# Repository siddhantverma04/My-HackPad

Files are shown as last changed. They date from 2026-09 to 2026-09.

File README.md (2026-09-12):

# My HackPad

A custom 3×3 macropad designed from scratch using KiCad, Fusion 360, and QMK.

The HackPad uses a Seeed Studio XIAO RP2040, 9 mechanical switches,
4 SK6812MINI-E RGB LEDs, a 128×32 OLED display, and custom QMK firmware.

## Features

- 3×3 mechanical key layout
- 4 SK6812MINI-E RGB LEDs
- 0.91" 128×32 SSD1306 OLED
- Seeed Studio XIAO RP2040
- Custom PCB
- Custom 3D-printed case
- QMK firmware

## HackPad Render



## Schematic



## PCB



## Case

The case was designed to fit the custom PCB, switches, OLED, and XIAO RP2040. 



## Firmware

The HackPad runs QMK firmware on the XIAO RP2040.

Current normal keymap:

| 1 | 2 | 3 |
|---|---|---|
| 4 | 5 | 6 |
| 7 | 8 | 9 |

Holding key 9 opens an RGB-control layer for changing effects,
hue, saturation, and brightness.

## Bill of Materials

| Component | Amount |
|---|---:|
| Seeed Studio XIAO RP2040 | 1 |
| Cherry MX-compatible switches | 9 |
| 1N4148 diodes | 9 |
| SK6812MINI-E RGB LEDs | 4 |
| 0.91" 128×32 SSD1306 OLED | 1 |
| 1U keycaps | 9 |
| Custom PCB | 1 |
| 3D-printed top case / plate(I will print myself) | 1 |
| 3D-printed bottom case(I will print myself) | 1 |
| M3 screws | 4 |
| M3 heat-set inserts | 4 |

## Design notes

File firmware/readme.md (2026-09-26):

# My Hackpad Firmware

QMK firmware for my custom 3x3 Hackpad.

## Hardware

- Seeed Studio XIAO RP2040
- 9 Cherry MX compatible switches
- 4 SK6812MINI-E RGB LEDs
- 0.91 inch 128x32 SSD1306 I2C OLED

## Firmware

Firmware is built using QMK Firmware.

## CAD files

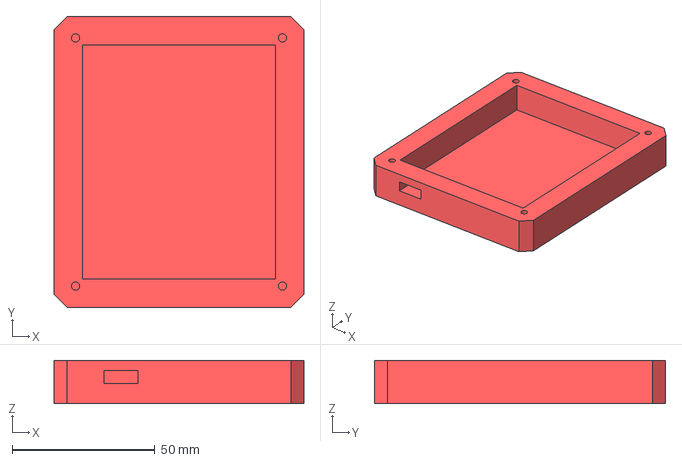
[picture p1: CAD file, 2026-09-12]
production/Bottom.step
87.5 x 102.0 x 15.2 mm

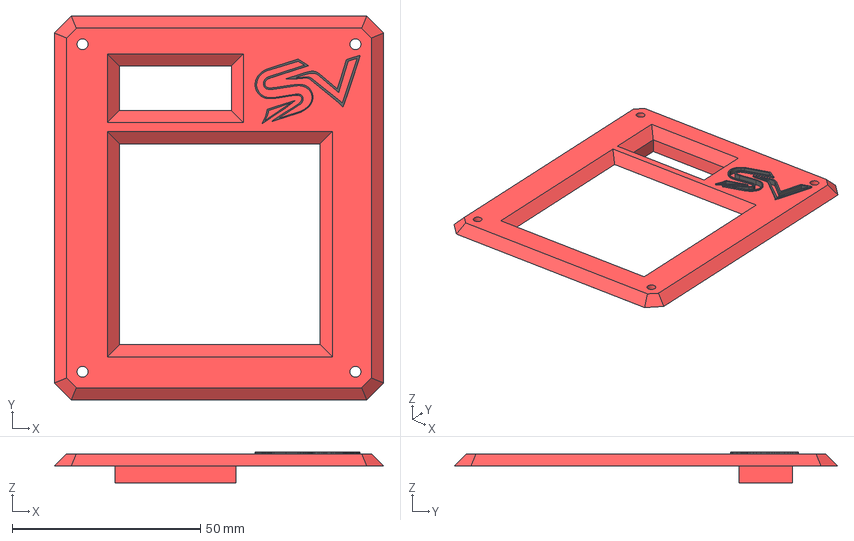
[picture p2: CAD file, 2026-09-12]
production/Top.step
87.5 x 102.0 x 8.15 mm

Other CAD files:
production/Bottom.3mf

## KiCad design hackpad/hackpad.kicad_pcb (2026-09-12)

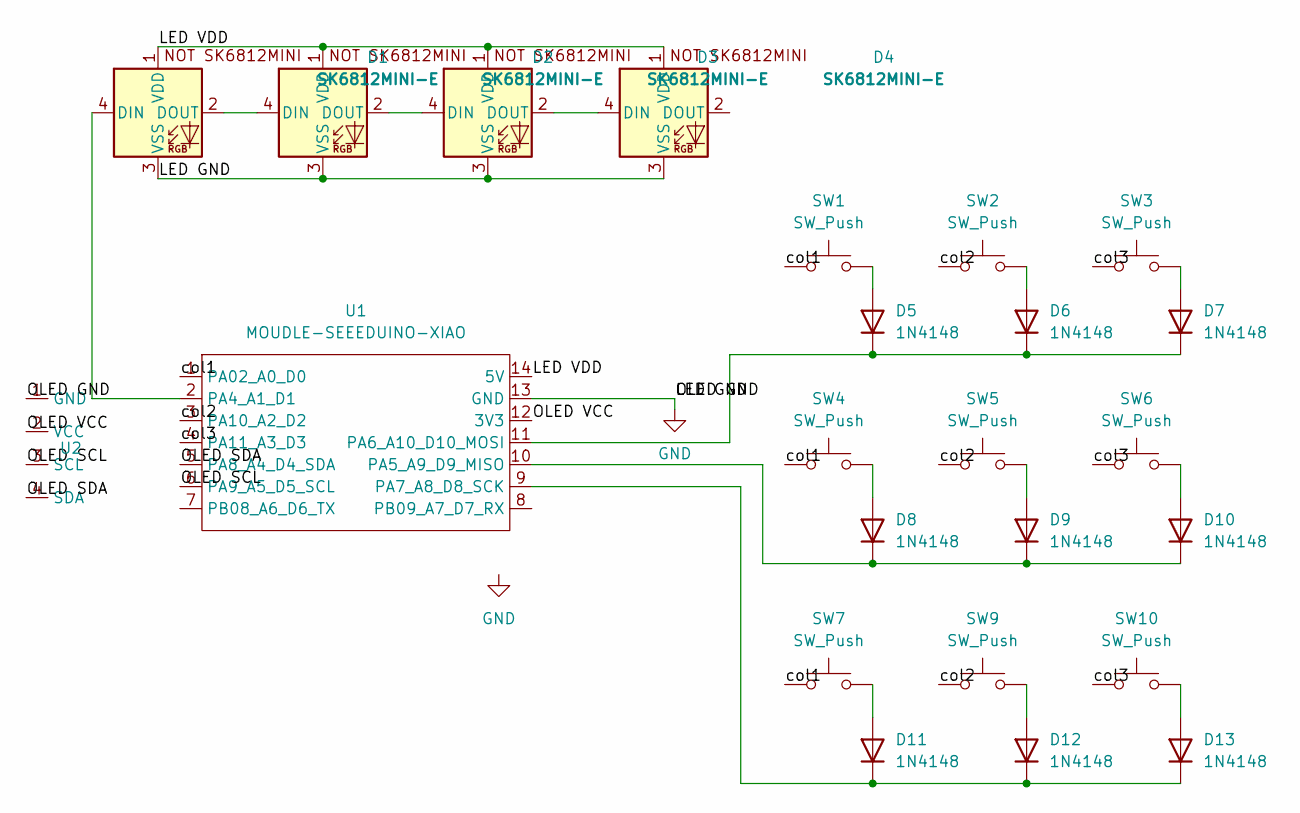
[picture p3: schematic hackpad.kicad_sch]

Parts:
D1, D2, D3, D4: SK6812MINI-E; LED_SK6812MINI-E_3.2x2.8mm_P1.5mm_ReverseMount
D5, D6, D7, D8, D9, D10, D11, D12, D13: 1N4148; D_DO-35_SOD27_P7.62mm_Horizontal
SW1, SW2, SW3, SW4, SW5, SW6, SW7, SW9, SW10: SW_Push; SW_Cherry_MX_1.00u_PCB
U1: MOUDLE-SEEEDUINO-XIAO; XIAO-Generic-Hybrid-14P-2.54-21X17.8MM
U2: SSD1306-0.91-OLED-4pin-128x32

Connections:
/<NO NET>: U1.5 (PA8_A4_D4_SDA), U2.4 (SDA)
/LED VDD: D1.1 (VDD), D2.1 (VDD), D3.1 (VDD), D4.1 (VDD), U1.14 (5V)
/OLED SCL: U1.6 (PA9_A5_D5_SCL), U2.3 (SCL)
/OLED VCC: U1.12 (3V3), U2.2 (VCC)
/col1: SW1.1, SW4.1, SW7.1, U1.1 (PA02_A0_D0)
/col2: SW2.1, SW5.1, SW9.1, U1.3 (PA10_A2_D2)
/col3: SW3.1, SW6.1, SW10.1, U1.4 (PA11_A3_D3)
GND: D1.3 (VSS), D2.3 (VSS), D3.3 (VSS), D4.3 (VSS), U1.13 (GND), U2.1 (GND)
unnamed: D1.4 (DIN), U1.2 (PA4_A1_D1)
unnamed: D1.2 (DOUT), D2.4 (DIN)
unnamed: D2.2 (DOUT), D3.4 (DIN)
unnamed: D3.2 (DOUT), D4.4 (DIN)
unnamed: D5.2 (A), SW1.2
unnamed: D5.1 (K), D6.1 (K), D7.1 (K), U1.11 (PA6_A10_D10_MOSI)
unnamed: D6.2 (A), SW2.2
unnamed: D7.2 (A), SW3.2
unnamed: D8.2 (A), SW4.2
unnamed: D9.2 (A), SW5.2
unnamed: D10.2 (A), SW6.2
unnamed: D8.1 (K), D9.1 (K), D10.1 (K), U1.10 (PA5_A9_D9_MISO)
unnamed: D11.2 (A), SW7.2
unnamed: D11.1 (K), D12.1 (K), D13.1 (K), U1.9 (PA7_A8_D8_SCK)
unnamed: D12.2 (A), SW9.2
unnamed: D13.2 (A), SW10.2

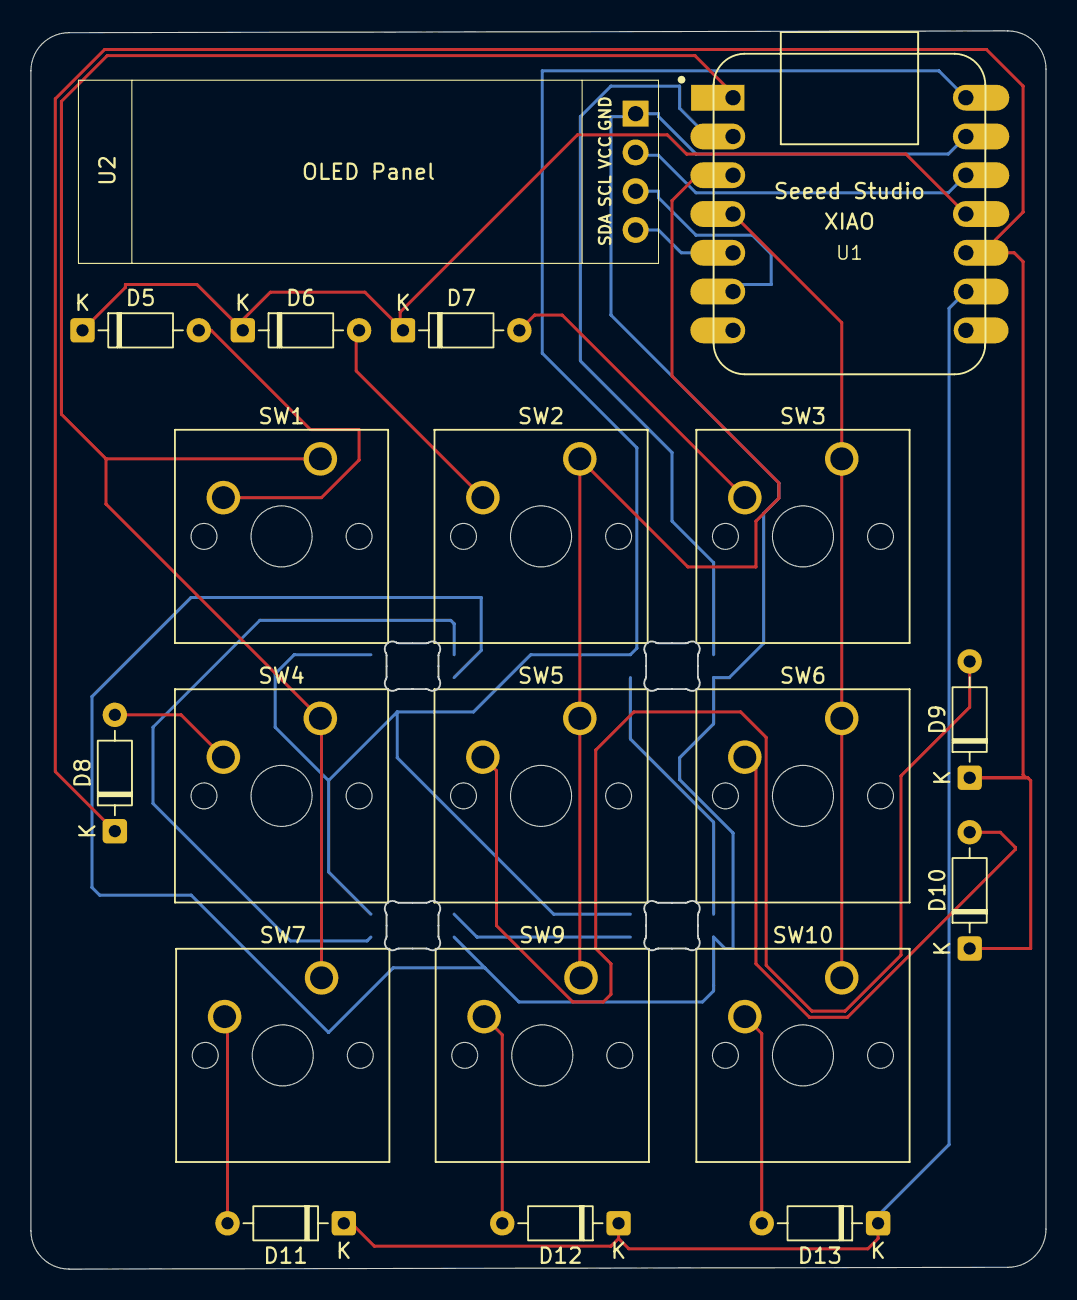
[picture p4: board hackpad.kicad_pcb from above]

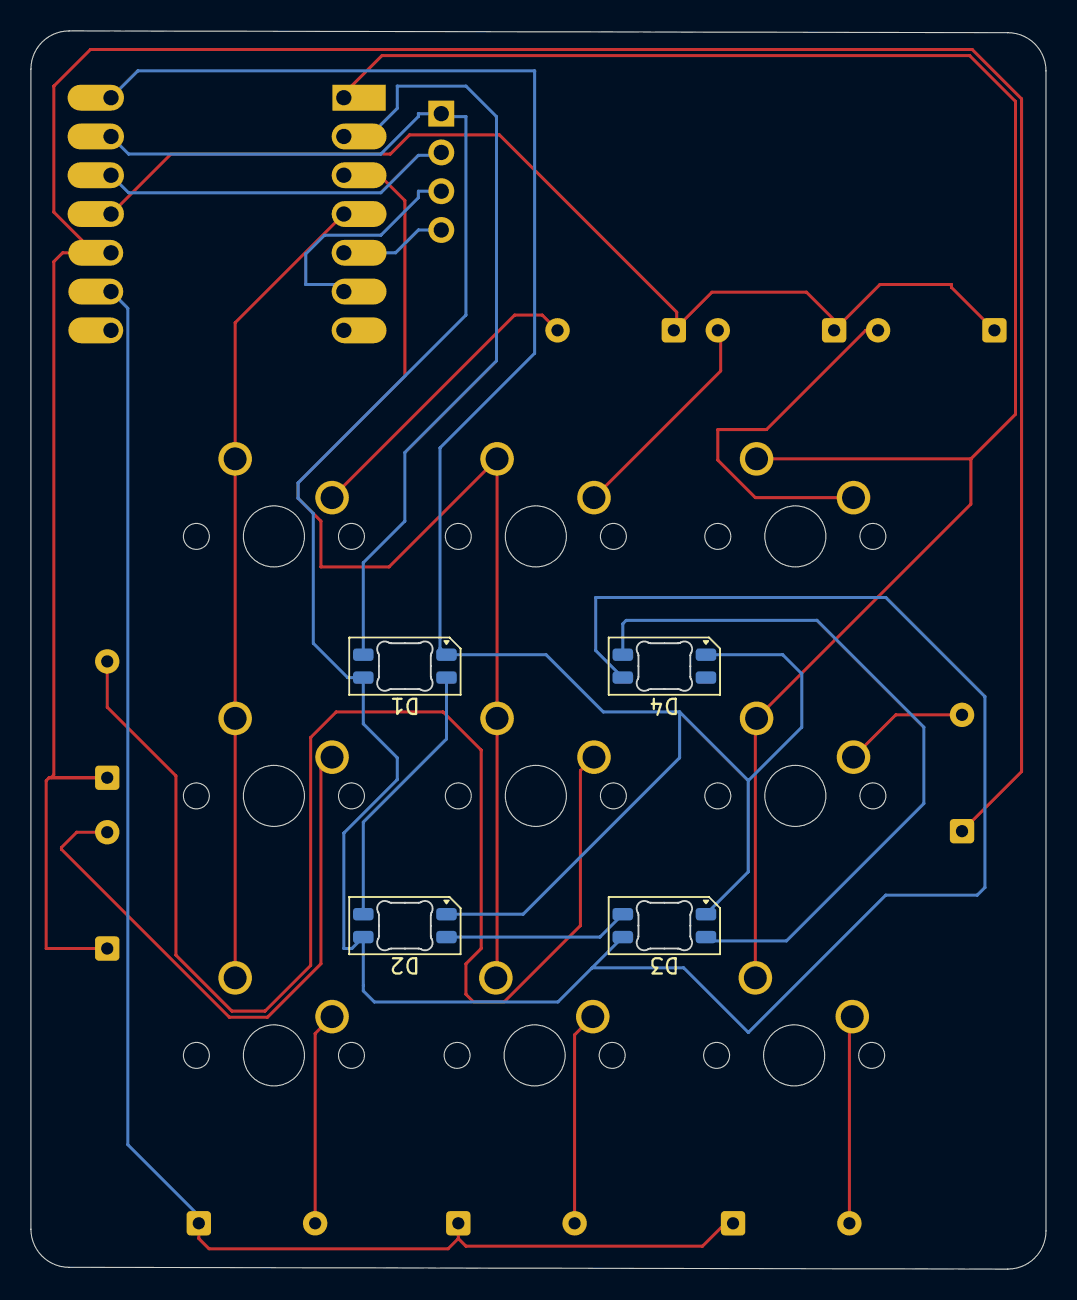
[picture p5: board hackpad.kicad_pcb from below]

Board: 2 copper layers, 66.5 x 81.1 mm, 24 parts (4 on the bottom side), 24 nets.

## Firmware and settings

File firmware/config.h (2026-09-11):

#pragma once

#define RGB_LIMIT_VAL 120
#define RGBLIGHT_SLEEP

#define I2C_DRIVER I2CD1
#define I2C1_SDA_PIN GP6
#define I2C1_SCL_PIN GP7

#define OLED_DISPLAY_ADDRESS 0x3C
#define OLED_BRIGHTNESS 128
#define OLED_TIMEOUT 60000

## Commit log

2026-08-24 Imported PCB
    [hackpad.kicad_pcb, hackpad.kicad_sch]
2026-09-01 Finished PCB
    [hackpad.kicad_pcb, hackpad.kicad_sch]
2026-09-05 Created PCB folder
2026-09-09 Adjusted Firmware for diodes.
    [hackpad.kicad_pcb, hackpad.kicad_sch]
2026-09-12 Setting up for submission
    [Bottom.step, Top.step, hackpad.kicad_pcb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]
2026-09-12 Set up for submission
    [hackpad-B_Cu.gbr, hackpad-B_Mask.gbr, hackpad-B_Silkscreen.gbr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]
2026-09-12 updated the bottom part of the case
    [Bottom.step]
2026-09-26 Updated firmware
    [Bottom.3mf, hackpad.kicad_sch]
2026-10-20 Remove KiCad lock files
    Delete the tracked project and schematic lock files.
2026-11-12 Add section for fully assembled hackpad
    Added a section for the fully assembled hackpad with an image.
